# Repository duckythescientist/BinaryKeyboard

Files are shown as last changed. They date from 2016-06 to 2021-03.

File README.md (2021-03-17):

# BinaryKeyboard
1 and 0 are the only keys a true programmer needs

Now with Unicode support! 

The keyboard

[Youtube](https://youtu.be/qHAFpK-0hug) and [Youtube](https://www.youtube.com/watch?v=DmWm68NnIkk)

[Gifycat](https://gfycat.com/SophisticatedWeepyButterfly)

[Imgur Album](http://imgur.com/a/icKnR)

In a fit of inspiration, I threw this together in an evening. It is a small keyboard with three keys: `0`, `1`, and `enter/submit`.

Unicode support happened a separate day. 

## Functionality

### Mode 0
The `0` key types a "0". The `1` key types a "1". The `enter/submit` key types the enter key.

### Mode 1
This is the true binary mode. To type an ASCII letter, press a combination of 8 `0`s and `1`s (MSB first) then press `enter/submit`. If you press `enter/submit` with greater or fewer than 8 bits, this clears all of the bits. This allows you to clear screwups without having any letters actually typed. 

### NEW: Unicode Hybrid Mode (1)
As a modification to "Mode 1", you can now enter Unicode characters!!! Instead of just typing 8 bits, type anywhere from 3 to 8 nibbles before pressing `enter/submit`. Typing exactly 8 bits will fallback to the standard Mode 1.

Unicode Support

[Gifv](https://i.imgur.com/321nCg8.gifv)

For Linux, the keyboard uses a modification of the CTRL+SHIFT+U method. It has been tested with Debian Jessie (Xfce) and partially tested with Ubuntu 14.04 (Unity).

For Windows, the keyboard uses the ALT+NUMPAD_PLUS hexadecimal method. This requires a registry edit. To `HKEY_CURRENT_USER\Control Panel\Input Method` add a string (`REG_SZ`) called `EnableHexNumpad` with the value `1` then reboot. Unfortunately, Windows doesn't seem to like anything more than 4 nibbles with this method. There are other methods, but this is the most universal for Windows. I'm very open to suggestions for ways to fix this. 

## Mode Selection:
When plugging in the USB cable, the keyboard will startup and default to Mode 0, QWERTY, Linux. 
* To switch to Mode 1, hold the `0` key when plugging in the keyboard. 
* To switch to Dvorak, hold `1` when plugging in the keyboard. 
* To switch to Windows Unicode mode, hold the `enter/submit` key when plugging in the keyboard. 

Key(s) must be held for around 7 seconds (dependent mostly on AUTO_EXIT_MS defined in the Micronucleus bootloader). 

## Construction
The body of the keyboard is 3D printed. Mine was done with a Monoprice Select Mini, but it's a small and forgiving design, so just about any printer should work.

The 4 keyswitches should be Cherry MX style. I'm using Gateron Blues. The 2u keycap needs double stems. This could be changed to fit a single stem or triple stem with stabilizers 2u keycap if the OpenSCAD files are changed. 

The controller is a "tinyDev" board of my creation. Order it from [PCBS.io](https://pcbs.io/share/8Dmor) or from [OSH Park](https://oshpark.com/shared_projects/nc7kkKFu) or elsewhere. Both PCBS.io and OSH Park are super cheap for small boards. 

The keyswitches share a common ground on one pin. The other pin connects directly to pins on the tinyDev. `0` to B1, `1` to B2, and `enter/submit` to B0. This can be easily changed in the code. 

Place the keyswitches in the top panel, solder the switches to the tinyDev, place the tinyDev into the base (add a little hot glue to keep it in place), and fit the top panel to the base (should be a snug press fit, if not, use glue). 

## Programming
The attiny85 on the tinyDev comes blank from the factory, so an ICSP such as the USB-ASP is needed to initially program it with the bootloader. A SOIC test clip helps immensely. The bootloader can be found [here](https://github.com/micronucleus/micronucleus). You may need/want to use the one that ships with the Digispark Arduino installation. 

Install the [Digispark boardstuffs](https://digistump.com/wiki/digispark/tutorials/connecting) to Arduino.

## BOM
Resistors and capacitors are generic 0805

2x 68ohm

1x 1.5kohm

1x 100nF

The two diodes are 3.6V zeners in a SOD-323F package. I used MM3Z3V6CCT-ND

The attiny is ATTINY85-20SURCT-ND

USB connector is Amphenol 10118194-0001LF (609-4618-1-ND on Digikey)

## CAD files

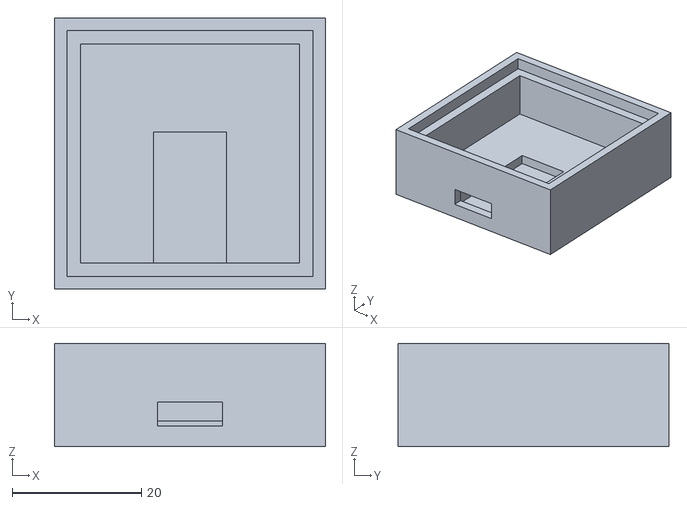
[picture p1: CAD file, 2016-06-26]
case/body.stl
42.0 x 42.0 x 16.0

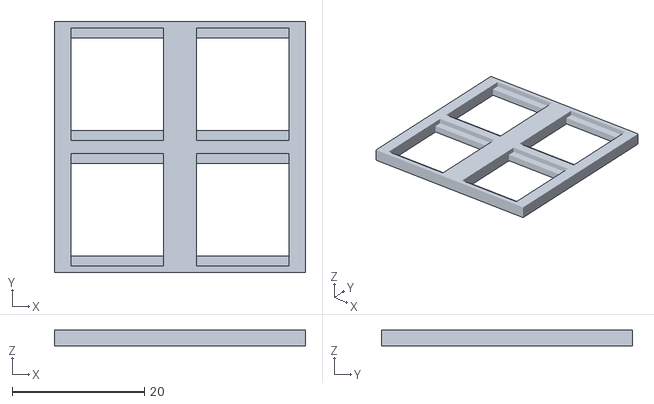
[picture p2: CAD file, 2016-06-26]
case/top.stl
38.0 x 38.0 x 2.40

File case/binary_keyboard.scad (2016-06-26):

epsilon = 0.1;

module mx_cutout(){  // origin at center, bottom view
    translate([-7,-7,-1]){
        union(){
            cube([14,14,5]);
            translate([0,-1.5,1+1.4]){
                cube([14,14+3,5]);
            }
        }
    }
}

module top_plate(){
    difference(){
        translate([-19,-19,0])
            cube([38,38,2.4]);
        translate([-9.5,-9.5,0])
            mx_cutout();
        translate([-9.5,+9.5,0])
            mx_cutout();
        translate([+9.5,+9.5,0])
            mx_cutout();
        translate([+9.5,-9.5,0])
            mx_cutout();
    }
}


module body(){
    difference(){
        cube([42,42,16]);  // main body
        translate([4,4,4])  // large cutout
            cube([34,34,16]);
        translate([2-epsilon,2-epsilon,16-2.4-epsilon])  // lip
            cube([38+2*epsilon,38+2*epsilon, 6]);
        translate([42/2 - 11.3/2, 2, 2])  // PCB
            cube([11.3, 22.3, 5]);
        translate([42/2 - 10/2, -1, 2+1.2])  // USB hole
            cube([10,6,3.7]);
    }
}



body();
translate([19+2, 19+2, 16]) scale([1,1,-1]) top_plate();

// body();
// top_plate();    
        

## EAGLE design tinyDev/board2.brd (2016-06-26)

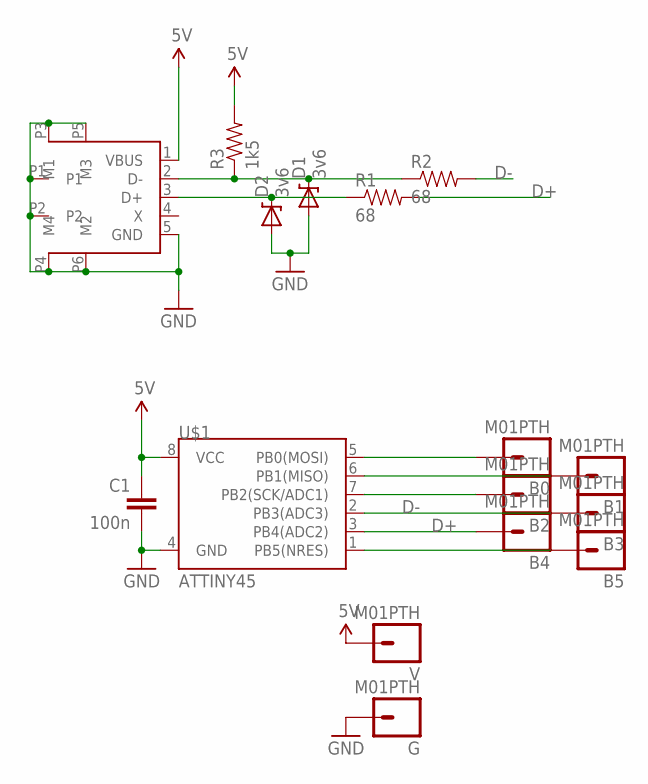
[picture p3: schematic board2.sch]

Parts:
B0, B1, B2, B3, B4, B5: M01PTH; 1X01
C1: 100n; 0805
CON1: USBMICRO-FCI; USBMINIB-10118194-0001LF
D1, D2: 3v6; SOD-323
G: M01PTH; 1X01
R1, R2: 68; 0805
R3: 1k5; 0805
U$1: ATTINY45; SO08-EIAJ
V: M01PTH; 1X01

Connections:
5V: C1.1, CON1.1 (VBUS), R3.2, U$1.8 (VCC), V.1
D+: B4.1, R1.2, U$1.3 (PB4(ADC2))
D-: B3.1, R2.2, U$1.2 (PB3(ADC3))
GND: C1.2, CON1.5 (GND), CON1.P1, CON1.P2, CON1.P3 (M1), CON1.P4 (M4), CON1.P5 (M3), CON1.P6 (M2), D1.2 (A), D2.2 (A), G.1, U$1.4 (GND)
unnamed: B0.1, U$1.5 (PB0(MOSI))
unnamed: B1.1, U$1.6 (PB1(MISO))
unnamed: B2.1, U$1.7 (PB2(SCK/ADC1))
unnamed: B5.1, U$1.1 (PB5(NRES))
unnamed: CON1.2 (D-), D1.1 (C), R2.1, R3.1
unnamed: CON1.3 (D+), D2.1 (C), R1.1

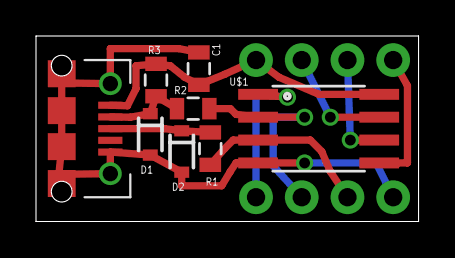
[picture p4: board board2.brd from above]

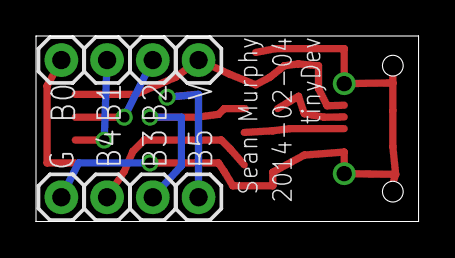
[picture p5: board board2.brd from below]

Board: 2 copper layers, 21.3 x 10.3 mm, 16 parts (8 on the bottom side), 10 nets.

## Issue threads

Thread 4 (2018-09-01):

What is the exact size, i.e., length, with and height of the case

Orcuslc, 2018-09-01:
Hi, I want to print the case with our school's 3D printing facilities, but it requires the exact size of the case. So I need to know the length, with and height in centimeters/inches. Thanks.

duckythescientist, 2018-09-02:
The top plate is 38x38x2.4 mm.
The body is 42x42x16 mm.

[case/binary_keyboard.scad](https://github.com/duckythescientist/BinaryKeyboard/blob/master/case/binary_keyboard.scad) has the dimensions.

Closed 2018-09-02.

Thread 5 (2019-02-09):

Could not get it to work

gokalpsterr, 2019-02-09:
I tried to build one for myself but for some reason I don't get any errors, but it just does not work (Nothing happens when I press the buttons in any mode).
I started the project like a year ago and after I didn't succeed, I left it for some time, today I checked again with the help of a programmer friend and we followed everything according to your guide but no luck.

Please help to solve what I am doing wrong.
Thank you @duckythescientist

duckythescientist, 2019-02-12:
I'm going to need more information than this. http://www.catb.org/esr/faqs/smart-questions.html#beprecise has some good suggestions.

Start by flashing the example DigiKeyboard script that comes with the Digispark install. This will narrow down the problem.

```cpp
#include "DigiKeyboard.h"

void setup() {
  // don't need to set anything up to use DigiKeyboard
}

void loop() {
  // this is generally not necessary but with some older systems it seems to
  // prevent missing the first character after a delay:
  DigiKeyboard.sendKeyStroke(0);

  // Type out this string letter by letter on the computer (assumes US-style
  // keyboard)
  DigiKeyboard.println("Hello Digispark!");

  // It's better to use DigiKeyboard.delay() over the regular Arduino delay()
  // if doing keyboard stuff because it keeps talking to the computer to make
  // sure the computer knows the keyboard is alive and connected
  DigiKeyboard.delay(5000);
}
```

gokalpsterr, 2019-02-13:
Okay, yeah you are right. I should have been more clear.

So first of all thanks for replying, I tested the piece of code you sent and it worked. It printed "Hello Digispark!" every 5 seconds as expected.

I also checked all of my (3) buttons with a multimeter and controlled if they are seen by the board and it seems as there is no hardware related issue so either I am trying to upload something wrong or maybe a library is corrupted.

What should I try next?

duckythescientist, 2019-02-15:
The compile/upload process should be the same as the snippet for the last comment, and the only library (other than the Arduino/Digispark internal stuffs) is `DigiKeyboard.h`, but we know that that is working.

When you plug in the keyboard, make sure you aren't pushing any of the buttons. It should default to "Mode 0" -- the simple mode where it types `0`, `1`, and `[enter]`. I just did a re-flash from a clean Arduino install, and everything is working for me. I was having some issues getting the board to flash, but that was a USB 2 vs 3 issue. Once flashed, that's no longer an issue.

Maybe take my code and cut it to the bare minimum where it only has that mode?

gokalpsterr, 2019-02-15:
Yeah, I exactly do the same process as I did to the comment that you sent, and it is so weird: It uploads and still when I boot without pressing any buttons, there is no reaction.
I tried a very simple (bare minimum) code and that didn't work either.

I guess the problem is that my Digispark board is not getting the inputs or at least behaves like, not sure what to do with them. The simple 1 / 0 / Enter didn't work at all so I guess it is definately about the inputs. (My buttons work individually but not registered by Digispark board)

Maybe I should burn bootloader again ? I mean It had one when it came and as I was successful with uploading a code, I didn't think it was necessary to do so. Should I try that or simply try all on another board just to be sure ?

Thanks for helping btw, I really appreciate it.

duckythescientist, 2019-02-20:
I wouldn't bother to burn the bootloader again, but that's not outside of the realm of possibility.

Double check your hardware? Make sure that your switches are wired to the correct pins on the Digispark and that the other side of the switches all go back to ground. Use a multimeter and measure the voltage on each Digispark pin (connected to a switch) with respect to ground. You should see about 5V when unpressed and 0V when pressed.

I'm not sure what else there is to try.

gokalpsterr, 2019-03-10:
So I found another one of those Attiny85 Digispark boards and that seemed a bit different, to be honest, and now that I tried I still have the same problem.
I try/do exactly as you say and it somehow doesn't work :(
I noticed that I didn't let you know about one thing though: when I press the button on some of the pins the board actually gets reset so I am wondering If I really should burn a new bootloader.
(the new one is fresh not even opened before)  Could you please send a picture of the board you have? I just want to check if we are on the same page.

Thank you

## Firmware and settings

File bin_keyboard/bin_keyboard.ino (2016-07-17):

#include "DigiKeyboard.h"

// Uncomment the following if you can't be bothered to patch DigiKeyboard with Dvorak support
// #define DigiKeyboard.write_dv DigiKeyboard.write

#define PIN0 (1<<1)
#define PIN1 (1<<2)
#define PINE (1<<0)

byte last_state[] = {0};
byte bmask[] = {PIN0, PIN1, PINE};
byte *my_keys;

byte qwerty_keys[] = {KEY_0, KEY_1, KEY_ENTER, 24};  // 0,1,ENTER,u
byte dvorak_keys[] = {KEY_0, KEY_1, KEY_ENTER, 9}; 

byte * my_numpad;
byte qwerty_numpad_keys[] = {0x62, 0x59, 0x5A, 0x5B, 0x5C, 0x5D, 0x5E, 0x5F, 0x60, 0x61, 4,5,6,7,8,9};  // numpad 0-9 a-f
byte dvorak_numpad_keys[] = {0x62, 0x59, 0x5A, 0x5B, 0x5C, 0x5D, 0x5E, 0x5F, 0x60, 0x61, 0x04,0x11,0x0c,0x0b,0x07,0x1C};  // numpad 0-9 a-f

unsigned long last_change[] = {0,0,0};
#define DEBOUNCE_TIME 25

byte mode = 0;
byte keymapmode = 0;
byte iswindows = 0;

void setup() {
  DDRB &= ~(PIN0 | PIN1 | PINE);  // All inputs
  PORTB |= (PIN0 | PIN1 | PINE);  // Pullups on
  DigiKeyboard.sendKeyStroke(0);  // Wakeup the keyboard
  DigiKeyboard.delay(50);  // Always use this delay instead of the builtin delay

  if(!(PINB & PIN0)) mode = 1;  // If "0" is pressed, switch to mode 1
  if(!(PINB & PIN1))  // If "1" is pressed, switch to Dvorak
  {
    my_keys = dvorak_keys;
    my_numpad = dvorak_numpad_keys;
    keymapmode = 1;
  }
  else
  {
    my_keys = qwerty_keys;
    my_numpad = qwerty_numpad_keys;
    keymapmode = 0;;
  }

  if(!(PINB & PINE)) iswindows = 1;


  while((PINB & (PIN0 | PIN1 | PINE)) != (PIN0 | PIN1 | PINE))
    DigiKeyboard.delay(100);  // Wait for switches to be idle
  

}

byte debounce()  // return mask for changed buttons
{
  byte ret = 0;
  for(byte i=0; i<3; i++)
  {
    if((PINB & bmask[i]) != last_state[i])
    {
      if(millis() - last_change[i] > DEBOUNCE_TIME)
      {
        last_state[i] = PINB & bmask[i];
        last_change[i] = millis();
        ret |= (1<<i);
      }
    }
  }
  return ret;
}

void mode_0()
{
  byte r = debounce();
  if(r)  // If any key is pressed
  {
    for(byte i=0; i<3; i++)  // For each key
    {
      if(r & (1<<i))  // If this key is pressed
      {
        if(!last_state[i])  // And it wasn't pressed last time we checked
        {
          // Send the corresponding letter
          DigiKeyboard.sendKeyStroke(my_keys[i]);
        }
      }
    }
  }
  else
  {
    //DigiKeyboard.sendKeyStroke(0);
    DigiKeyboard.delay(10);
  }
}


void write_unicode(unsigned long sval, byte count)
{
  // sanity check
  if(count < 8 || (count % 4))
    return;

  // For standard ASCII, just type the letter the simple way
  if(count == 8 && sval < 0x80)
  {
    if(keymapmode)
    {
      DigiKeyboard.write_dv(byte(sval & 0x7F));
    }
    else
    {
      DigiKeyboard.write(byte(sval & 0x7F));
    }
  }
  else
  {

    // Windows Unicode method:
    // HKEY_CURRENT_USER\Control Panel\Input Method contains a string type (REG_SZ) value called EnableHexNumpad, which has the value data 1
    // Note, Windows seems to only type 2-byte symbols.
    // There are other methods that may have more symbols, but this is more universal.
    // Hold ALT, type numpad_plus, type hexadecimal value, release alt

    // Linux Unicode method:
    // Note, this may be X specific or application specific.
    // I've had success in Ubuntu 14.04 with Unity (Chrome, Guake, Gedit, Sublime Text 3)
    // Type CTRL+[ALT]+SHIFT+U and release, type hexadecimal value (%x not %8x), type space 
    // Some applications need the ALT, and some don't. It seems to work to do both.


    byte charbuf[10];
    byte charcount = 0;

  /*
    // Convert to (reversed) decimal
    // Not needed because of Windows registry edit
    while(sval > 0)
    {
      byte decval = sval % 10;
      charbuf[charcount] = numpad_keys[decval];
      charcount += 1;
      sval /= 10;
    }
  */

    // Convert to (reversed) hexadecimal
    while(count > 0)
    {
      byte hexval = byte(sval&0xF);  // Get the low nibble
      charbuf[charcount] = my_numpad[hexval];  // Save hexadecimal nibble as ascii letter
      charcount += 1;
      count -= 4;
      sval >>=4;
    }


    if(iswindows)
    {
      DigiKeyboard.sendKeyPress(0x57, MOD_ALT_LEFT);  // NUMPAD_PLUS

      // Write out charbuf backward
      while(charcount>0)
      {
        DigiKeyboard.sendKeyPress(charbuf[--charcount], MOD_ALT_LEFT);
        // DigiKeyboard.sendKeyStroke(charbuf[--charcount]);  // debug
      }

      DigiKeyboard.sendKeyPress(0);  // release alt (everything)
    }
    else
    {
      // CTRL+ALT+SHIFT+U
      DigiKeyboard.sendKeyStroke(my_keys[3], MOD_CONTROL_LEFT | MOD_SHIFT_LEFT | MOD_ALT_LEFT);
      
      // CTRL+SHIFT+U
      DigiKeyboard.sendKeyStroke(my_keys[3], MOD_CONTROL_LEFT | MOD_SHIFT_LEFT);


      // Write out charbuf backward
      while(charcount>0)
      {
        DigiKeyboard.sendKeyStroke(charbuf[--charcount]);
      }

      DigiKeyboard.sendKeyStroke(KEY_SPACE);
    }

  }

}

void mode_1()
{
  byte count = 0;  // How many bits have been entered
  unsigned long sval = 0;  // Actual cumulative value for the bits
  while(1)
  {
    DigiKeyboard.delay(10);
    byte r = debounce();
    if(r)  // If any key has been pressed
    {
      if(r & (1<<2))  // If "submit" has been pressed
      {
        if(!last_state[2])  // And it wasn't previously pressed
        {
          if(count < 8 || (count % 4))  // Bad number of bits for character
          {
            //DigiKeyboard.write('0' + count);
            // Clear the count and clear the bits
            sval = 0;
            count = 0;
          }
          else  // good number of bits were pressed so actually type a letter
          {
            write_unicode(sval, count);
            sval = 0;
            count = 0;
          }
        }
      }
      else  // other key pressed
      {
        if((r & (1<<1)) && !last_state[1])  // "1" pressed
        {
          sval <<= 1;
          count ++;
          sval |= 1;
        }
        else if((r & (1<<0)) && !last_state[0])  // "0" pressed
        {
          sval <<= 1;
          count ++;
        }
      }
    }
  }
}

void loop() {
  switch(mode)
  {
    case 0:
      mode_0();
      break;
    case 1:
      mode_1();
      break;
    default:
      mode_0();
      break;
  }

}

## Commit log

2016-06-26 Add case scad and stls
    [binary_keyboard.scad, body.stl, top.stl]
2016-06-26 Add Arduino code
2016-06-26 Add board files
    [board2.brd, board2.sch]
2021-03-17 Update readme with BOM

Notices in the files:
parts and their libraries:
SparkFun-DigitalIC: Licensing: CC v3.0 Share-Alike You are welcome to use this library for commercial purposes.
